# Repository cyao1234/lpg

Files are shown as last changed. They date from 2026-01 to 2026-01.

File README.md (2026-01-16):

# UC ULP GMSS & LTE-M SiP DK

This is a high efficiency ULP SIP GMSS, NBIoT & LTE-M nRF91 STO LTS for IOT with minimal BOM, ultra-low Iq and dedicated STO PHY (IP). It operates with an advanced LP PSM paired with an low iDRX interval RRC idle to optimize RX dBm gain using cDRX variations and variable iDRX PDCCH.

With integrated FETs, LNA and FIDOs, it becomes the perfect LPWA GMSS & NBIoT DK. The only external UE needed is an active IPEX U.FE RoHS MHFI antenna (50 ohms) connected to the on-board SWF. It enables remote HWFC TXD via SWO thanks to it's subscriber identity module.



## Features

- 3x3cm UC footprint
- < 500uA current consumtion
- Embedded UART FTDI TXD via USB 2.0
- External MMC (32MiB)
- GPIO breakouts
- IPEX U.FE MHFI ANT connectors
- JST PH B2B LiPo connection
- Self contained



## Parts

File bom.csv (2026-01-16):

Item | Price | Source
PCB + PCBA | 254.24$ | jlc
sdcard slot | 0.12$ | https://fr.aliexpress.com/item/1005007526763190.html
lipo | 3.82$ | https://www.aliexpress.com/item/1005009836119485.html
Aliexpress shipping | 6.86$ | -
H2B4MH1F2F0100 LTE/4G Full band | 4.21$ | https://www.digikey.fr/fr/products/detail/unictron-technologies-corporation/H2B4MH1F2F0100/9921462
1475-1006-ND ANT CER PATCH Active CAB | 7.23$ | https://www.digikey.fr/fr/products/detail/inventek-systems/ACTPAT182-01-IP/4488765
Digikey shipping | 22.00$ | -

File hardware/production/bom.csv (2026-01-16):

Designator | Footprint | Quantity | Value | LCSC Part #
C1, C13, C19, C5, C6 | 0402 | 5 | 4.7uF | C23733
C10, C16, C17, C18, C3, C8, C9 | 0402 | 7 | 100nF | C60474
C11, C12 | 0402 | 2 | 56pF | C107007
C14, C15, C20 | 0402 | 3 | 10uF | C315248
C2, C7 | 0603 | 2 | 47uF | C140782
C4 | 0402 | 1 | 15pF | C1548
D1, D3 | 0402 | 2 | LED | C779449
FB1 | 0402 | 1 | 120R/0.7A | C88970
J1, J2 | U.FL_Hirose_U.FL-R-SMT-1_Vertical | 2 | GPS | C392444
J3 | SMN-304 | 1 | SIM_Card_Shielded | C266889
J4 | USB_C_Receptacle_HRO_TYPE-C-31-M-12 | 1 | USB_C_Receptacle_USB2.0_14P | C165948
J5 | JST_PH_B2B-PH-K_1x02_P2.00mm_Vertical | 1 | LiPo | C2319
L1 | 0402 | 1 | 68n 200mA | C391307
Q1 | SC-89 | 1 | RE1C002UNTCL | C509959
R1, R3 | 0402 | 2 | 100k | C25741
R10 | 0402 | 1 | 10M | C26082
R11, R8, R9 | 0402 | 3 | 5.1k | C25905
R12, R2, R5 | 0402 | 3 | 1k | C11702
R13 | 0402 | 1 | 402 | C2933096
R6 | 0402 | 1 | 1M | C26083
R7 | 0402 | 1 | 249k | C11425
SW2 | EU-01KS | 1 | SW_DIP_x01 | C47817623
U1 | Nordic_nRF9160-SIxx_LGA-102-59EP_16.0x10.5mm_P0.5mm | 1 | nRF9160-SICA | C1518973
U2 | TDFN-4-1.2x1.6 | 1 | SIP32409DNP | C145277
U3 | VSON-8-1EP_3x3mm_P0.65mm_EP1.65x2.4mm_ThermalVias | 1 | TPS2113A | C354512
U4 | LGA-12_2x2mm_P0.5mm | 1 | LIS2DH12TR | C110926
U5 | VCF0007A-MFG | 1 | TPSM828438 | C44545617
U6 | DFN-8-1EP_2x2mm_P0.5mm_EP0.9x1.6mm | 1 | TP4056-DFN | C49208530
U8 | QFN-20-1EP_4x4mm_P0.5mm_EP2.5x2.5mm | 1 | FT231XQ | C132159
U9 | Winbond_USON-8-1EP_3x2mm_P0.5mm_EP0.2x1.6mm | 1 | ZD25WQ32C | C5258281

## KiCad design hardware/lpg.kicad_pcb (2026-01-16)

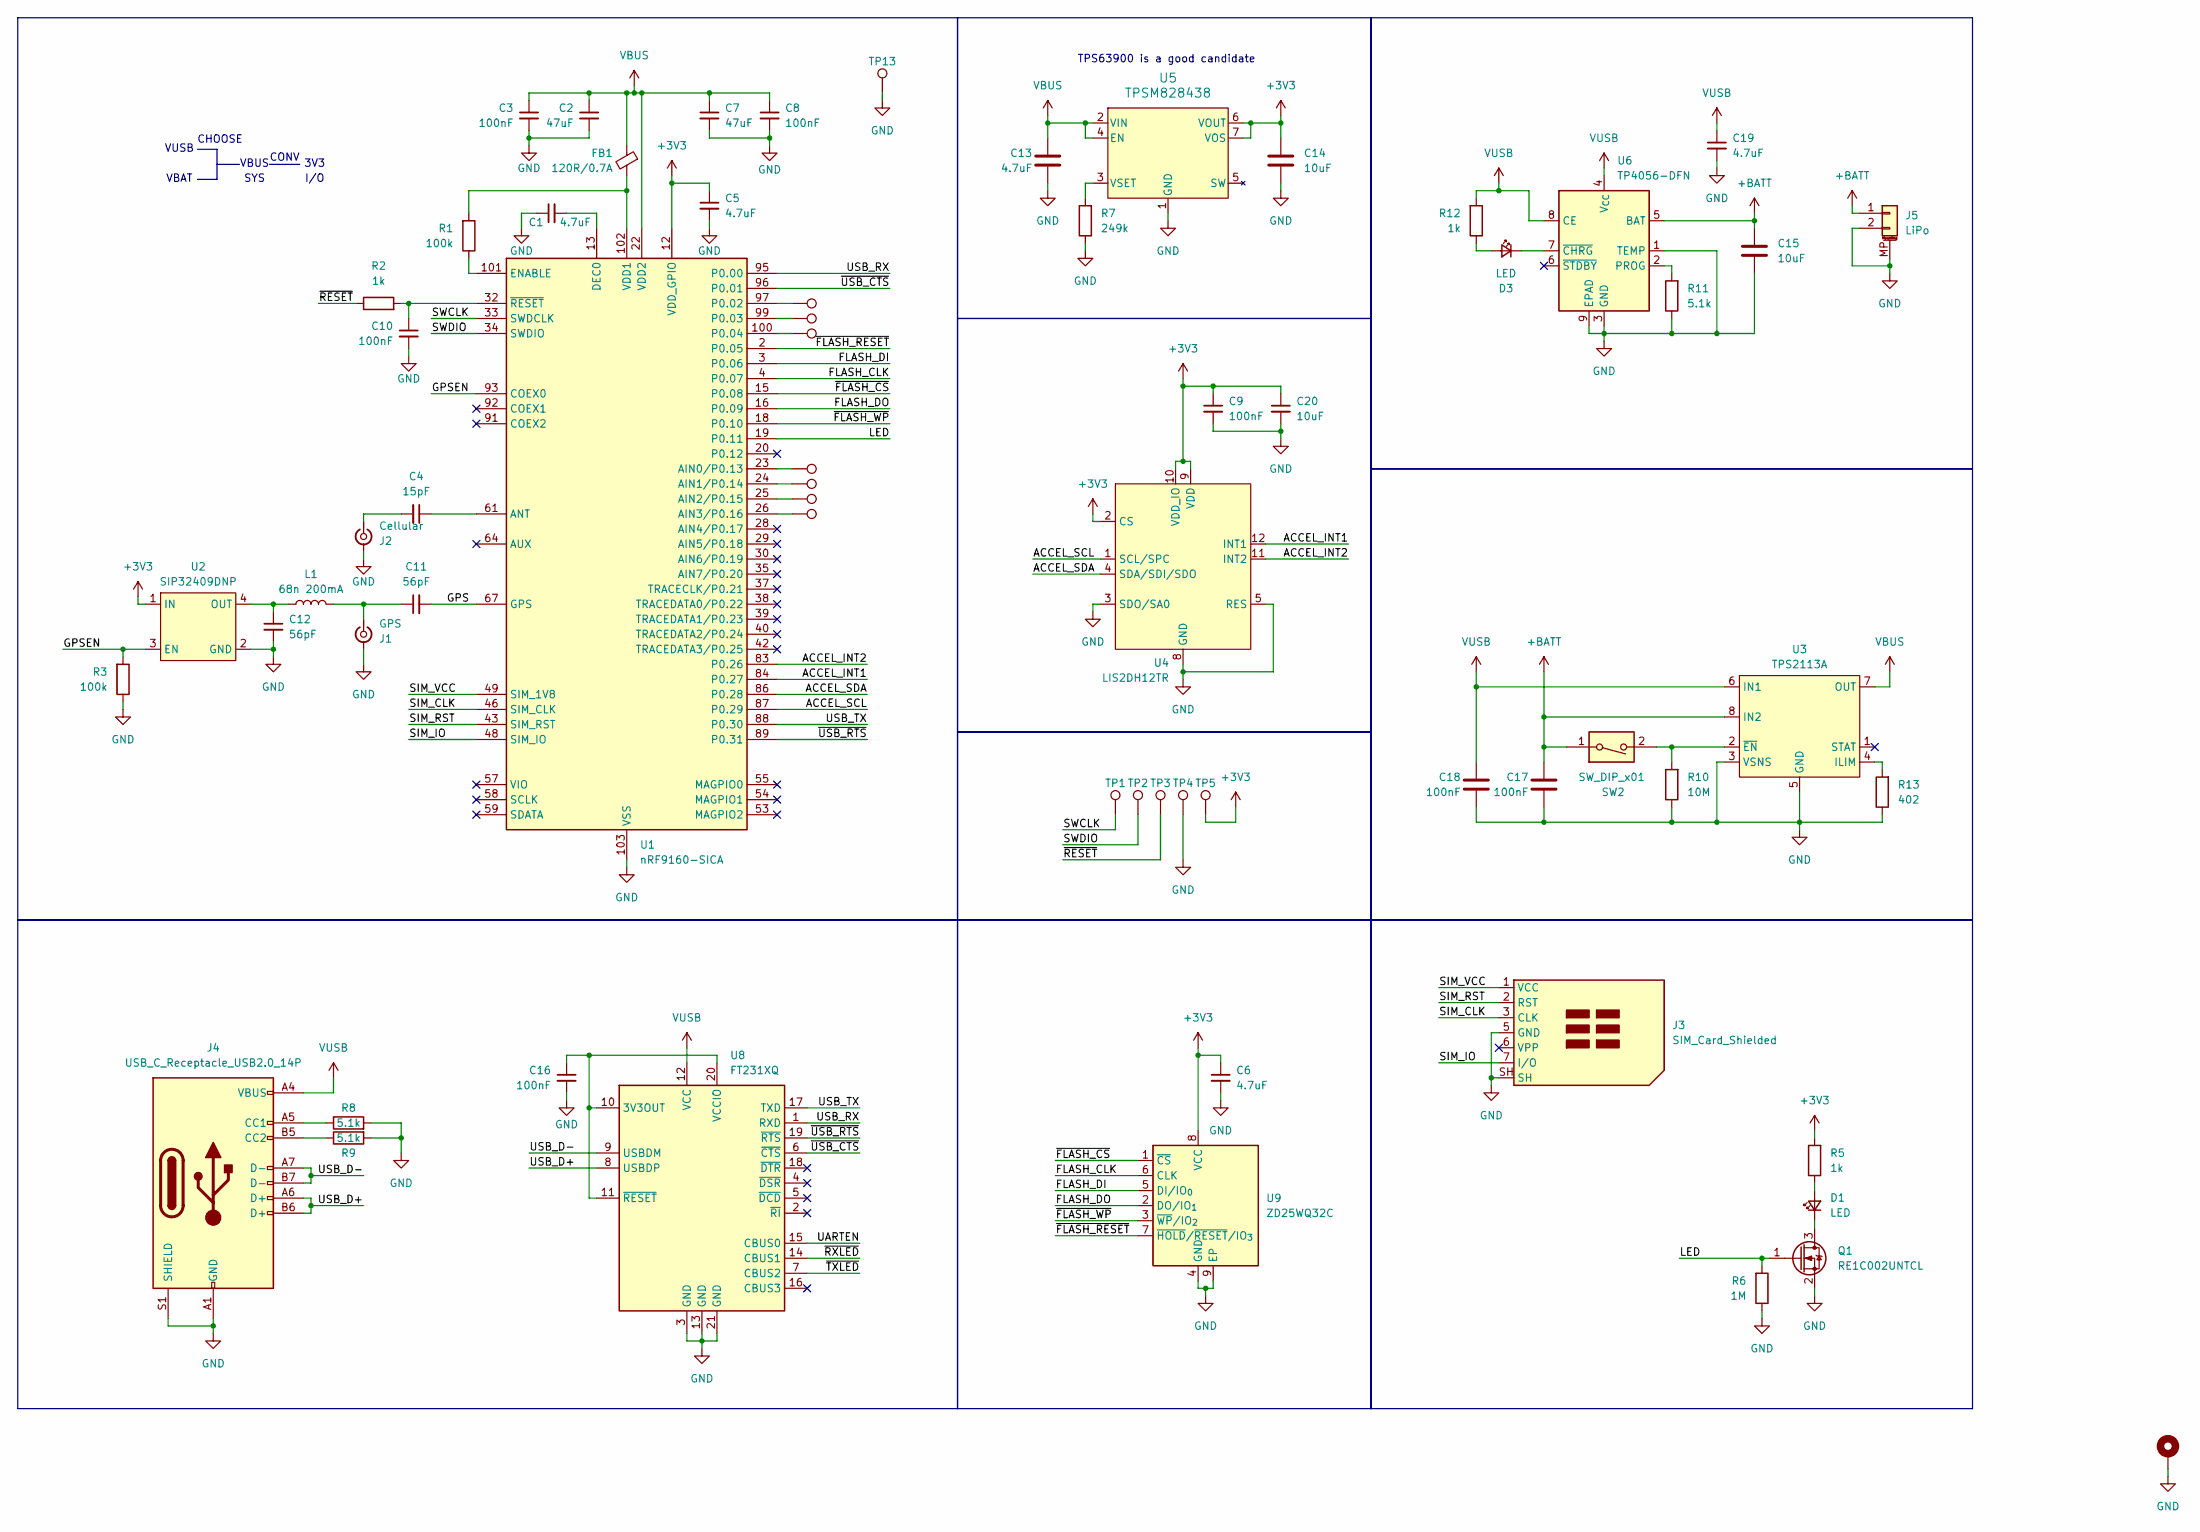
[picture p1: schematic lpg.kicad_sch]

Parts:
C1, C5, C6, C13, C19: 4.7uF; C_0402_1005Metric; LCSC Part # C23733
C2, C7: 47uF; C_0603_1608Metric; LCSC Part # C140782
C3, C8, C9, C10, C16, C17, C18: 100nF; C_0402_1005Metric; LCSC Part # C60474
C4: 15pF; C_0402_1005Metric; LCSC Part # C1548
C11, C12: 56pF; C_0402_1005Metric; LCSC Part # C107007
C14, C15, C20: 10uF; C_0402_1005Metric; LCSC Part # C315248
D1, D3: LED; LED_0402_1005Metric; LCSC Part # C779449
FB1: 120R/0.7A; L_0402_1005Metric; LCSC Part # C88970
H1: MountingHole_Pad_MP; MountingHole_2.2mm_M2
J1: GPS; U.FL_Hirose_U.FL-R-SMT-1_Vertical; LCSC Part # C88374
J2: Cellular; U.FL_Hirose_U.FL-R-SMT-1_Vertical; LCSC Part # C88374
J3: SIM_Card_Shielded; SMN-304; LCSC Part # C266889
J4: USB_C_Receptacle_USB2.0_14P; USB_C_Receptacle_HRO_TYPE-C-31-M-12; LCSC Part # C165948
J5: LiPo; JST_PH_B2B-PH-K_1x02_P2.00mm_Vertical; LCSC Part # C2319
L1: 68n 200mA; L_0402_1005Metric; LCSC Part # C391307
Q1: RE1C002UNTCL; SC-89; LCSC Part # C509959
R1, R3: 100k; R_0402_1005Metric; LCSC Part # C25741
R2, R5, R12: 1k; R_0402_1005Metric; LCSC Part # C11702
R6: 1M; R_0402_1005Metric; LCSC Part # C26083
R7: 249k; R_0402_1005Metric; LCSC Part # C11425
R8, R9, R11: 5.1k; R_0402_1005Metric; LCSC Part # C25905
R10: 10M; R_0402_1005Metric; LCSC Part # C26082
R13: 402; R_0402_1005Metric; LCSC Part # C2933096
SW2: SW_DIP_x01; EU-01KS; LCSC Part # C47817623
TP1, TP2, TP3, TP4, TP5, TP6, TP7, TP8, TP9, TP10, TP11, TP12, TP13: TestPoint; TestPoint_Pad_D1.5mm
U1: nRF9160-SICA; Nordic_nRF9160-SIxx_LGA-102-59EP_16.0x10.5mm_P0.5mm; LCSC Part # C1518973
U2: SIP32409DNP; TDFN-4-1.2x1.6; LCSC Part # C145277
U3: TPS2113A; VSON-8-1EP_3x3mm_P0.65mm_EP1.65x2.4mm_ThermalVias; LCSC Part # C354512
U4: LIS2DH12TR; LGA-12_2x2mm_P0.5mm; LCSC Part # C110926
U5: TPSM828438; VCF0007A-MFG; LCSC Part # C44545617
U6: TP4056-DFN; DFN-8-1EP_2x2mm_P0.5mm_EP0.9x1.6mm; LCSC Part # C49208530
U8: FT231XQ; QFN-20-1EP_4x4mm_P0.5mm_EP2.5x2.5mm; LCSC Part # C132159
U9: ZD25WQ32C; Winbond_USON-8-1EP_3x2mm_P0.5mm_EP0.2x1.6mm; LCSC Part # C5258281

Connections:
+3V3: C5.1, C6.1, C9.1, C14.1, C20.1, R5.2, TP5.1, U1.12 (VDD_GPIO), U2.1 (IN), U4.2 (CS), U4.9 (VDD), U4.10 (VDD_IO), U5.6 (VOUT), U5.7 (VOS), U9.8 (VCC)
+BATT: C15.1, C17.1, J5.1, SW2.1, U3.8 (IN2), U6.5 (BAT)
/ACCEL_INT1: U1.84 (P0.27), U4.12 (INT1)
/ACCEL_INT2: U1.83 (P0.26), U4.11 (INT2)
/ACCEL_SCL: U1.87 (P0.29), U4.1 (SCL/SPC)
/ACCEL_SDA: U1.86 (P0.28), U4.4 (SDA/SDI/SDO)
/FLASH_CLK: U1.4 (P0.07), U9.6 (CLK)
/FLASH_DI: U1.3 (P0.06), U9.5 (DI/IO_{0})
/FLASH_DO: U1.16 (P0.09), U9.2 (DO/IO_{1})
/GPS: C11.2, U1.67 (GPS)
/GPSEN: R3.2, U1.93 (COEX0), U2.3 (EN)
/LED: Q1.1 (G), R6.2, U1.19 (P0.11)
/SIM_CLK: J3.3 (CLK), U1.46 (SIM_CLK)
/SIM_IO: J3.7 (I/O), U1.48 (SIM_IO)
/SIM_RST: J3.2 (RST), U1.43 (SIM_RST)
/SIM_VCC: J3.1 (VCC), U1.49 (SIM_1V8)
/SWCLK: TP1.1, U1.33 (SWDCLK)
/SWDIO: TP2.1, U1.34 (SWDIO)
/UARTEN: U8.15 (CBUS0)
/USB_D+: J4.A6 (D+), J4.B6 (D+), U8.8 (USBDP)
/USB_D-: J4.A7 (D-), J4.B7 (D-), U8.9 (USBDM)
/USB_RX: U1.95 (P0.00), U8.1 (RXD)
/USB_TX: U1.88 (P0.30), U8.17 (TXD)
/~FLASH_CS: U1.15 (P0.08), U9.1 (~CS)
/~FLASH_RESET: U1.2 (P0.05), U9.7 (~HOLD/~RESET/IO_{3})
/~FLASH_WP: U1.18 (P0.10), U9.3 (~WP/IO_{2})
/~RESET: R2.1, TP3.1
/~RXLED: U8.14 (CBUS1)
/~TXLED: U8.7 (CBUS2)
/~USB_CTS: U1.96 (P0.01), U8.6 (~CTS)
/~USB_RTS: U1.89 (P0.31), U8.19 (~RTS)
GND: C1.1, C2.2, C3.2, C5.2, C6.2, C7.2, C8.2, C9.2, C10.2, C12.2, C13.2, C14.2, C15.2, C16.2, C17.2, C18.2, C19.2, C20.2, H1.MP, J1.2 (Ext), J2.2 (Ext), J3.5 (GND), J3.SH, J4.A1 (GND), J4.A12 (GND), J4.B1 (GND), J4.B12 (GND), J4.S1 (SHIELD), J5.2, J5.MP (MountPin), Q1.2 (S), R3.1, R6.1, R7.1, R8.2, R9.2, R10.1, R11.1, R13.1, TP4.1, TP13.1, U1.1 (GND_Shield), U1.5 (GND_Shield), U1.6 (GND_Shield), U1.7 (GND_Shield), U1.8 (GND_Shield), U1.9 (GND_Shield), U1.11 (GND_Shield), U1.14 (GND_Shield), U1.17 (GND_Shield), U1.21 (GND_Shield), U1.27 (GND_Shield), U1.31 (GND_Shield), U1.36 (GND_Shield), U1.41 (GND_Shield), U1.44 (GND_Shield), U1.47 (GND_Shield), U1.50 (GND_Shield), U1.52 (GND_Shield), U1.56 (GND_Shield), U1.60 (GND_Shield), U1.62 (GND_Shield), U1.63 (GND_Shield), U1.65 (GND_Shield), U1.66 (GND_Shield), U1.68 (GND_Shield), U1.69 (GND_Shield), U1.72 (GND_Shield), U1.74 (GND_Shield), U1.75 (GND_Shield), U1.76 (GND_Shield), U1.77 (GND_Shield), U1.78 (GND_Shield), U1.79 (GND_Shield), U1.80 (GND_Shield), U1.81 (GND_Shield), U1.82 (GND_Shield), U1.85 (GND_Shield), U1.90 (GND_Shield), U1.94 (GND_Shield), U1.98 (GND_Shield), U1.103 (VSS), U2.2 (GND), U2.5 (GND), U3.3 (VSNS), U3.5 (GND), U3.9 (GND), U4.3 (SDO/SA0), U4.5 (RES), U4.6 (GND), U4.7 (GND), U4.8 (GND), U5.1 (GND), U6.1 (TEMP), U6.3 (GND), U6.9 (EPAD), U8.3 (GND), U8.13 (GND), U8.21 (GND), U9.4 (GND), U9.9 (EP)
unnamed: D1.2 (A), R5.1
unnamed: D1.1 (K), Q1.3 (D)
unnamed: D3.2 (A), R12.1
unnamed: D3.1 (K), U6.7 (~CHRG)
unnamed: C11.1, J1.1 (In), L1.2
unnamed: C4.2, J2.1 (In)
unnamed: J4.A5 (CC1), R8.1
unnamed: J4.B5 (CC2), R9.1
unnamed: TP9.1, U1.23 (AIN0/P0.13)
unnamed: TP10.1, U1.24 (AIN1/P0.14)
unnamed: TP11.1, U1.25 (AIN2/P0.15)
unnamed: TP12.1, U1.26 (AIN3/P0.16)
unnamed: C4.1, U1.61 (ANT)
unnamed: C1.2, U1.13 (DEC0)
unnamed: R1.1, U1.101 (ENABLE)
unnamed: TP8.1, U1.97 (P0.02)
unnamed: TP7.1, U1.99 (P0.03)
unnamed: TP6.1, U1.100 (P0.04)
unnamed: FB1.2, R1.2, U1.102 (VDD1)
unnamed: C10.1, R2.2, U1.32 (~RESET)
unnamed: C12.1, L1.1, U2.4 (OUT)
unnamed: R13.2, U3.4 (ILIM)
unnamed: R10.2, SW2.2, U3.2 (~EN)
unnamed: R7.2, U5.3 (VSET)
unnamed: R11.2, U6.2 (PROG)
unnamed: C16.1, U8.10 (3V3OUT), U8.11 (~RESET), U8.20 (VCCIO)
VBUS: C2.1, C3.1, C7.1, C8.1, C13.1, FB1.1, U1.22 (VDD2), U3.7 (OUT), U5.2 (VIN), U5.4 (EN)
VUSB: C18.1, C19.1, J4.A4 (VBUS), J4.A9 (VBUS), J4.B4 (VBUS), J4.B9 (VBUS), R12.2, U3.6 (IN1), U6.4 (V_{CC}), U6.8 (CE), U8.12 (VCC)

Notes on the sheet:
VUSB
VBAT
I/O
3V3
VBUS
CHOOSE
TPS63900 is a good candidate
CONV
SYS

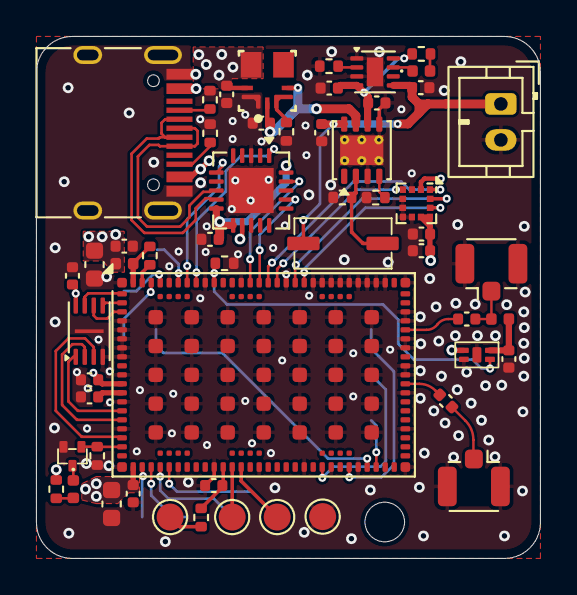
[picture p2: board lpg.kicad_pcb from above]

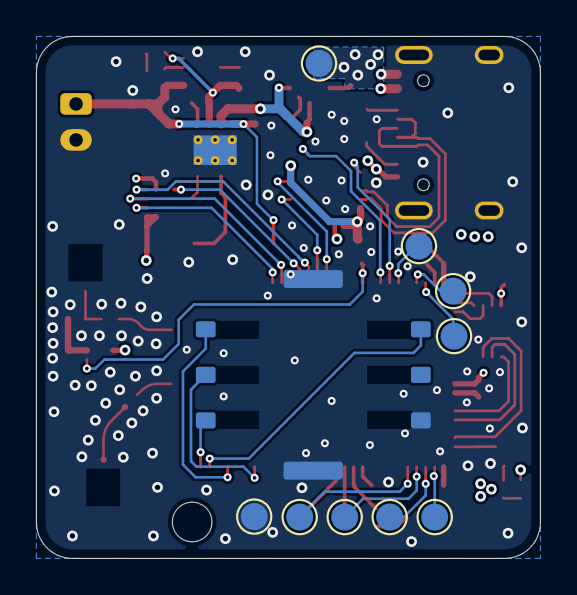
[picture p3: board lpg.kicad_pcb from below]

Board: 4 copper layers, 28.0 x 29.0 mm, 65 parts (10 on the bottom side), 57 nets.
